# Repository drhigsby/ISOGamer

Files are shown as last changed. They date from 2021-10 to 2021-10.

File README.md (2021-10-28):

# ISOGamer
 ISOGamer is a uniform staggered van-like keyboard that supports 2x ISO keys and a left-sided rotary encoder.

ISOGamer

Required Hardware for stacked case design:

-4x binding barrels https://www.mcmaster.com/93121A337/

-14x m2 5mm flat head screws https://www.aliexpress.com/item/4000067543700.html

-4x m2 5mm round standoffs  https://www.aliexpress.com/item/4000022968613.html

-6x m2 8mm flat head screws https://www.aliexpress.com/item/4000067543700.html

-6x m2 8mm round standoffs https://www.aliexpress.com/item/4000022968613.html

-1.5mm rubber bumpons (for mounting the plate)

-diodes(smd or tht)

-PM or equivalent

-rotary encoder (optional)

-switches

-keycaps

-2x3u stabilizers (for 2x3u bar option) OR 1x6.25u stabilizer (for 6.25u bar option)

KLE: http://www.keyboard-layout-editor.com/#/gists/59bec7c24a2eacc7034534ae54d9d0a9

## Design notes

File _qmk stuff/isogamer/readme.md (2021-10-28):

# ISOGamer

ISOGamer

 ISOGamer is a traditionally staggered van-like keyboard that supports 2x ISO keys and a left-sided rotary encoder. 

* Keyboard Maintainer: [DrHigsby](https://github.com/DrHigsby)
* Hardware Supported: (source not available at this time)
* Hardware Availability: Bring your own case.

Make example for this keyboard (after setting up your build environment):

    make isogamer:default

See the [build environment setup](https://docs.qmk.fm/#/getting_started_build_tools) and the [make instructions](https://docs.qmk.fm/#/getting_started_make_guide) for more information. Brand new to QMK? Start with our [Complete Newbs Guide](https://docs.qmk.fm/#/newbs).

KLE: http://www.keyboard-layout-editor.com/#/gists/59bec7c24a2eacc7034534ae54d9d0a9

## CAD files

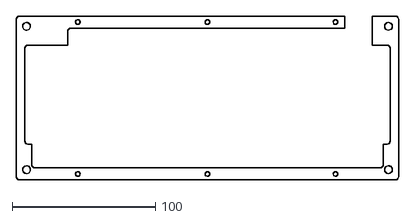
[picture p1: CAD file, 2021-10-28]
_case/DXFs/SAS ISOGamer Compression Layer 1x (3mm thick).dxf
266.7 x 114.3

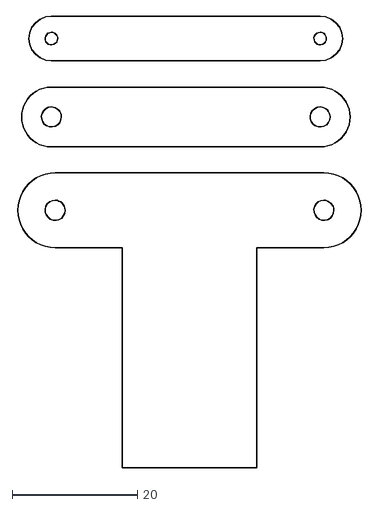
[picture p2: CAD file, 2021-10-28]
_case/DXFs/SAS ISOGamer PM Cover 1x (3mm thick).dxf
55.3 x 72.0

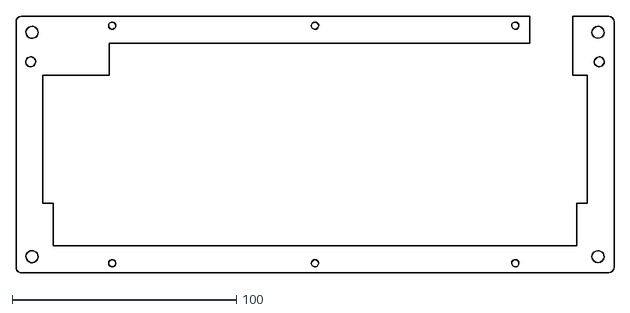
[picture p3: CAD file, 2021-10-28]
_case/DXFs/SAS ISOGamer Middle Layer 1x (3mm thick).dxf
266.7 x 114.3

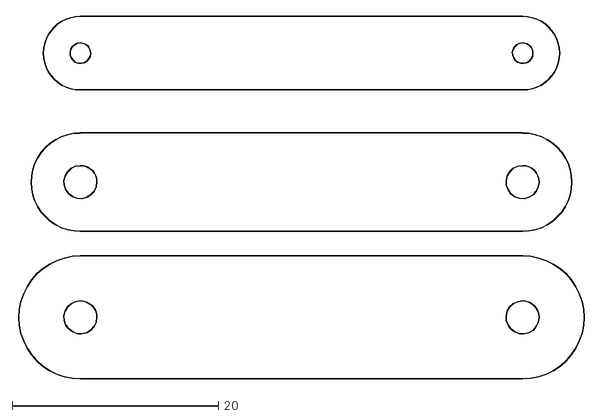
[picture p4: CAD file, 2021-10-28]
_case/DXFs/SAS ISOGamer Feet 1x (3mm thick).dxf
55.3 x 35.1

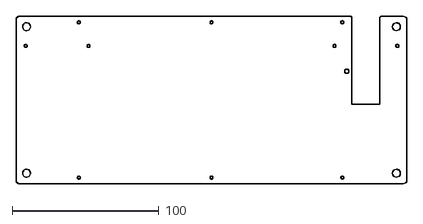
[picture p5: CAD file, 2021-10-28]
_case/DXFs/SAS ISOGamer Bottom Layer 1x (3mm thick).dxf
266.7 x 114.3

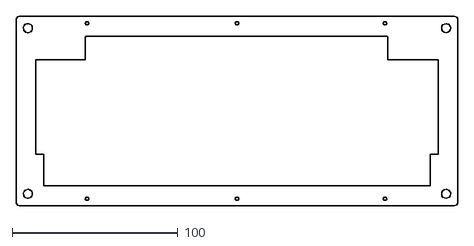
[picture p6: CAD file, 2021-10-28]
_case/DXFs/SAS ISOGamer Top Layer 2x (3mm thick).dxf
266.7 x 114.3

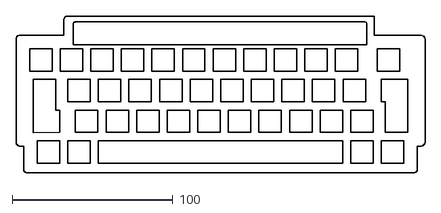
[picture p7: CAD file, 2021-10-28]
_case/DXFs/SAS ISOGamer Plate 1x (1.5mm or 1.6mm thick).dxf
254.8 x 97.6

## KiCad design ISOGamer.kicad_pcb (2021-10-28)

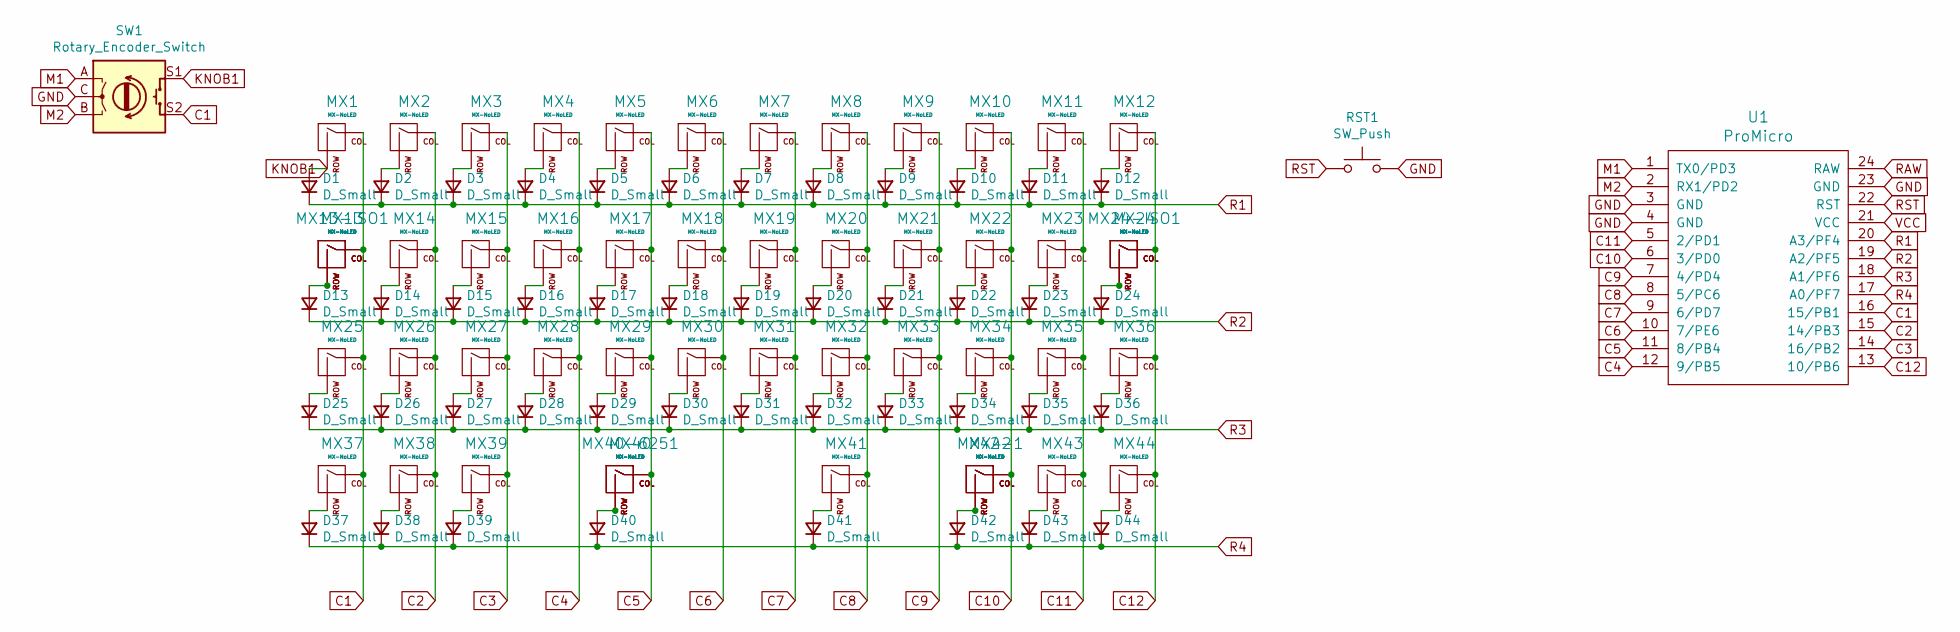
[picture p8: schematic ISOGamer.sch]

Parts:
D1, D2, D3, D4, D5, D6, D7, D8, D9, D10, D11, D12, D13, D14, D15, D16, D17, D18, D19, D20, D21, D22, D23, D24, D25, D26, D27, D28, D29, D30, D31, D32, D33, D34, D35, D36, D37, D38, D39, D40, D41, D42, D43, D44: D_Small; Diode-Hybrid-Back
MX1, MX2, MX3, MX4, MX5, MX6, MX7, MX8, MX9, MX10, MX11, MX14, MX15, MX16, MX17, MX18, MX19, MX20, MX21, MX22, MX23, MX26, MX27, MX28, MX29, MX30, MX31, MX32, MX33, MX34, MX35, MX37, MX38, MX39, MX42-1, MX43, MX44: MX-NoLED; MXOnly-1U-NoLED
MX12: MX-NoLED; MXOnly-1.75U-NoLED
MX13, MX36, MX42: MX-NoLED; MXOnly-1.25U-NoLED
MX13-ISO1, MX24-ISO1: MX-NoLED; MXOnly-ISO-ROTATED
MX24, MX25: MX-NoLED; MXOnly-1.5U-NoLED
MX40, MX41: MX-NoLED; MXOnly-3U-ReversedStabilizers-NoLED
MX40-6251: MX-NoLED; MXOnly-6.25U-ReversedStabilizers-NoLED
RST1: SW_Push; SW_SPST_TL3342
SW1: Rotary_Encoder_Switch; RotaryEncoder_Alps_EC11E-Switch_Vertical_H20mm_CircularMoun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
U1: ProMicro; ArduinoProMicro

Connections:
C1: MX1.1 (COL), MX13.1 (COL), MX13-ISO1.1 (COL), MX25.1 (COL), MX37.1 (COL), SW1.S2, U1.16 (15/PB1)
C2: MX2.1 (COL), MX14.1 (COL), MX26.1 (COL), MX38.1 (COL), U1.15 (14/PB3)
C3: MX3.1 (COL), MX15.1 (COL), MX27.1 (COL), MX39.1 (COL), U1.14 (16/PB2)
C4: MX4.1 (COL), MX16.1 (COL), MX28.1 (COL), U1.12 (9/PB5)
C5: MX5.1 (COL), MX17.1 (COL), MX29.1 (COL), MX40.1 (COL), MX40-6251.1 (COL), U1.11 (8/PB4)
C6: MX6.1 (COL), MX18.1 (COL), MX30.1 (COL), U1.10 (7/PE6)
C7: MX7.1 (COL), MX19.1 (COL), MX31.1 (COL), U1.9 (6/PD7)
C8: MX8.1 (COL), MX20.1 (COL), MX32.1 (COL), MX41.1 (COL), U1.8 (5/PC6)
C9: MX9.1 (COL), MX21.1 (COL), MX33.1 (COL), U1.7 (4/PD4)
C10: MX10.1 (COL), MX22.1 (COL), MX34.1 (COL), MX42.1 (COL), MX42-1.1 (COL), U1.6 (3/PD0)
C11: MX11.1 (COL), MX23.1 (COL), MX35.1 (COL), MX43.1 (COL), U1.5 (2/PD1)
C12: MX12.1 (COL), MX24.1 (COL), MX24-ISO1.1 (COL), MX36.1 (COL), MX44.1 (COL), U1.13 (10/PB6)
GND: RST1.2, SW1.C, U1.3 (GND), U1.4 (GND), U1.23 (GND)
KNOB1: D1.2 (A), MX1.2 (ROW), SW1.S1
M1: SW1.A, U1.1 (TX0/PD3)
M2: SW1.B, U1.2 (RX1/PD2)
unnamed: D2.2 (A), MX2.2 (ROW)
unnamed: D3.2 (A), MX3.2 (ROW)
unnamed: D4.2 (A), MX4.2 (ROW)
unnamed: D5.2 (A), MX5.2 (ROW)
unnamed: D6.2 (A), MX6.2 (ROW)
unnamed: D7.2 (A), MX7.2 (ROW)
unnamed: D8.2 (A), MX8.2 (ROW)
unnamed: D9.2 (A), MX9.2 (ROW)
unnamed: D10.2 (A), MX10.2 (ROW)
unnamed: D11.2 (A), MX11.2 (ROW)
unnamed: D12.2 (A), MX12.2 (ROW)
unnamed: D13.2 (A), MX13.2 (ROW), MX13-ISO1.2 (ROW)
unnamed: D14.2 (A), MX14.2 (ROW)
unnamed: D15.2 (A), MX15.2 (ROW)
unnamed: D16.2 (A), MX16.2 (ROW)
unnamed: D17.2 (A), MX17.2 (ROW)
unnamed: D18.2 (A), MX18.2 (ROW)
unnamed: D19.2 (A), MX19.2 (ROW)
unnamed: D20.2 (A), MX20.2 (ROW)
unnamed: D21.2 (A), MX21.2 (ROW)
unnamed: D22.2 (A), MX22.2 (ROW)
unnamed: D23.2 (A), MX23.2 (ROW)
unnamed: D24.2 (A), MX24.2 (ROW), MX24-ISO1.2 (ROW)
unnamed: D25.2 (A), MX25.2 (ROW)
unnamed: D26.2 (A), MX26.2 (ROW)
unnamed: D27.2 (A), MX27.2 (ROW)
unnamed: D28.2 (A), MX28.2 (ROW)
unnamed: D29.2 (A), MX29.2 (ROW)
unnamed: D30.2 (A), MX30.2 (ROW)
unnamed: D31.2 (A), MX31.2 (ROW)
unnamed: D32.2 (A), MX32.2 (ROW)
unnamed: D33.2 (A), MX33.2 (ROW)
unnamed: D34.2 (A), MX34.2 (ROW)
unnamed: D35.2 (A), MX35.2 (ROW)
unnamed: D36.2 (A), MX36.2 (ROW)
unnamed: D37.2 (A), MX37.2 (ROW)
unnamed: D38.2 (A), MX38.2 (ROW)
unnamed: D39.2 (A), MX39.2 (ROW)
unnamed: D40.2 (A), MX40.2 (ROW), MX40-6251.2 (ROW)
unnamed: D41.2 (A), MX41.2 (ROW)
unnamed: D42.2 (A), MX42.2 (ROW), MX42-1.2 (ROW)
unnamed: D43.2 (A), MX43.2 (ROW)
unnamed: D44.2 (A), MX44.2 (ROW)
R1: D1.1 (K), D2.1 (K), D3.1 (K), D4.1 (K), D5.1 (K), D6.1 (K), D7.1 (K), D8.1 (K), D9.1 (K), D10.1 (K), D11.1 (K), D12.1 (K), U1.20 (A3/PF4)
R2: D13.1 (K), D14.1 (K), D15.1 (K), D16.1 (K), D17.1 (K), D18.1 (K), D19.1 (K), D20.1 (K), D21.1 (K), D22.1 (K), D23.1 (K), D24.1 (K), U1.19 (A2/PF5)
R3: D25.1 (K), D26.1 (K), D27.1 (K), D28.1 (K), D29.1 (K), D30.1 (K), D31.1 (K), D32.1 (K), D33.1 (K), D34.1 (K), D35.1 (K), D36.1 (K), U1.18 (A1/PF6)
R4: D37.1 (K), D38.1 (K), D39.1 (K), D40.1 (K), D41.1 (K), D42.1 (K), D43.1 (K), D44.1 (K), U1.17 (A0/PF7)
RAW: U1.24 (RAW)
RST: RST1.1, U1.22 (RST)
VCC: U1.21 (VCC)

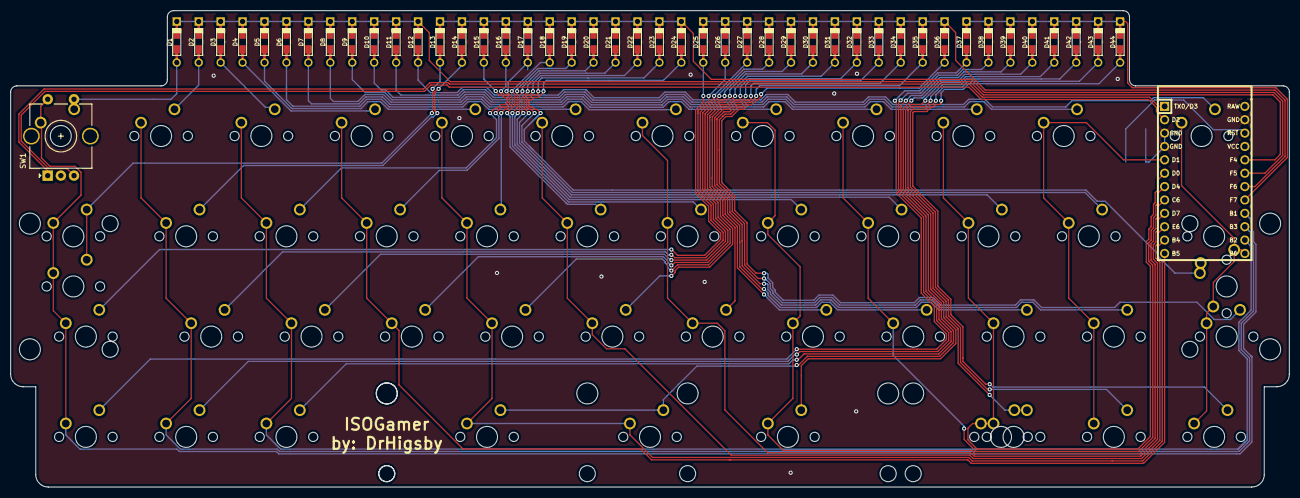
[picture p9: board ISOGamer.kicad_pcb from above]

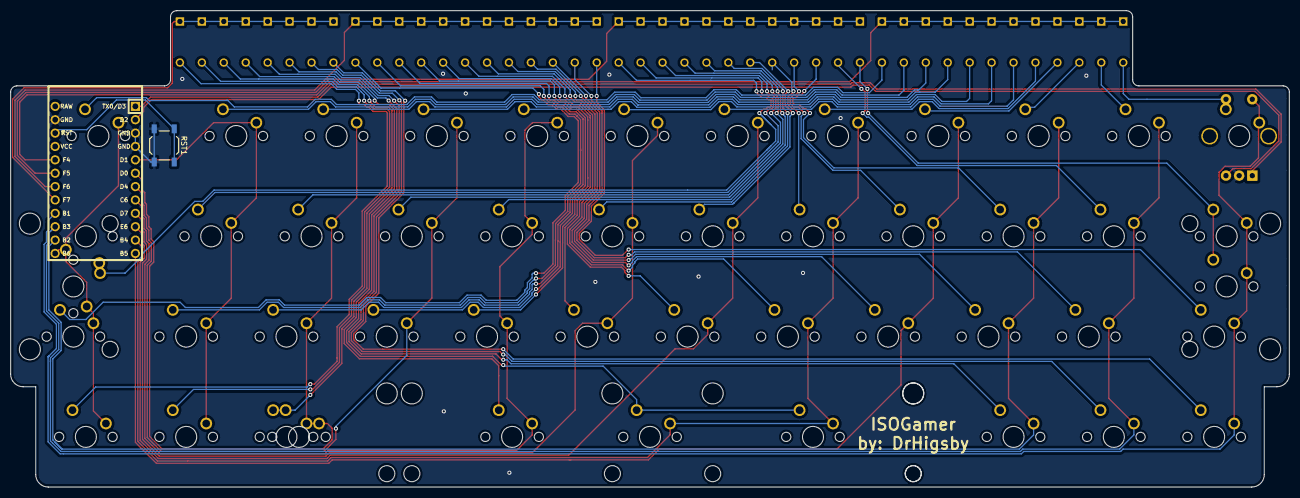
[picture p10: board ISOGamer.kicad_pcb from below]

Board: 2 copper layers, 242.9 x 90.5 mm, 95 parts (45 on the bottom side), 64 nets.

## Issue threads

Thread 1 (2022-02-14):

Assembly notes

Gordonby, 2022-02-14:
Loving the design 🥇

Full disclosure, I'm a newbie custom keyboards but have done a little reading on https://www.40percent.club/

It'd be great to see some assembly notes for the board. Not sure if there's a blog post etc in the mix?

I've loaded the gerber files into jlcpcb.com - ($27 for 5, delivered) - but there's going to be a bunch of components that aren't on the board in order to build it, but I'll be damned if I know what they are 😨

drhigsby, 2022-02-14:
Heya, lets chat about this in discord? DrRatsby#0007

On Mon, Feb 14, 2022 at 12:40 AM Gordon Byers ***@***.***>
wrote:

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

Gordonby, 2022-02-17:
Sure, I'll reach out once I've finished my gherkin board - IsoGamer can be next 🚀

drhigsby, 2022-02-20:
Sounds good! I have a discord server that I’ve invited my keeb friends to where I have channels dedicated to specific projects. I don’t think I have one set up for ISOGamer, but I can set one up and you can also chat with a few others who have built one.

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

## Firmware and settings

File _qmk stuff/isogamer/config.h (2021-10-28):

#pragma once

#include "config_common.h"

/* USB Device descriptor parameter */
#define VENDOR_ID 0x0007
#define PRODUCT_ID 0x0007
#define DEVICE_VER 0x0001
#define MANUFACTURER DrHigsby
#define PRODUCT ISOGamer

/* key matrix size */
#define MATRIX_ROWS 4
#define MATRIX_COLS 12

/*
 * Keyboard Matrix Assignments
 *
 * Change this to how you wired your keyboard
 * COLS: AVR pins used for columns, left to right
 * ROWS: AVR pins used for rows, top to bottom
 * DIODE_DIRECTION: COL2ROW = COL = Anode (+), ROW = Cathode (-, marked on diode)
 *                  ROW2COL = ROW = Anode (+), COL = Cathode (-, marked on diode)
 *
 */
#define MATRIX_ROW_PINS { F4, F5, F6, F7 }
#define MATRIX_COL_PINS { B1, B3, B2, B5, B4, E6, D7, C6, D4, D0, D1, B6 }
#define UNUSED_PINS

/* COL2ROW, ROW2COL*/
#define DIODE_DIRECTION COL2ROW

/* Debounce reduces chatter (unintended double-presses) - set 0 if debouncing is not needed */
#define DEBOUNCE 5

/* Mechanical locking support. Use KC_LCAP, KC_LNUM or KC_LSCR instead in keymap */
#define LOCKING_SUPPORT_ENABLE
/* Locking resynchronize hack */
#define LOCKING_RESYNC_ENABLE

/* Define encoder pads */
#define ENCODERS_PAD_A { D3 }
#define ENCODERS_PAD_B { D2 }

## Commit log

2021-10-28 updating case files
    [SAS ISOGamer Middle Layer (with feet cutout) 1x.dxf, SAS ISOGamer Middle Layer 1x.dxf, SAS ISOGamer Plate 1x (1.6mm MAX).dxf]
2021-10-28 updating case file names
    [SAS ISOGamer Bottom Layer 1x (3mm thick).dxf, SAS ISOGamer Compression Layer 1x (3mm thick).dxf, SAS ISOGamer Feet 1x (3mm thick).dxf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]
